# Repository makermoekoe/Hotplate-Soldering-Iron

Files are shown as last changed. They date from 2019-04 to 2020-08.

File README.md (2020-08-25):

# Hotplate Soldering Iron

__For more informations to this project you can visit my website [makermoekoe.com](https://www.makermoekoe.com)__

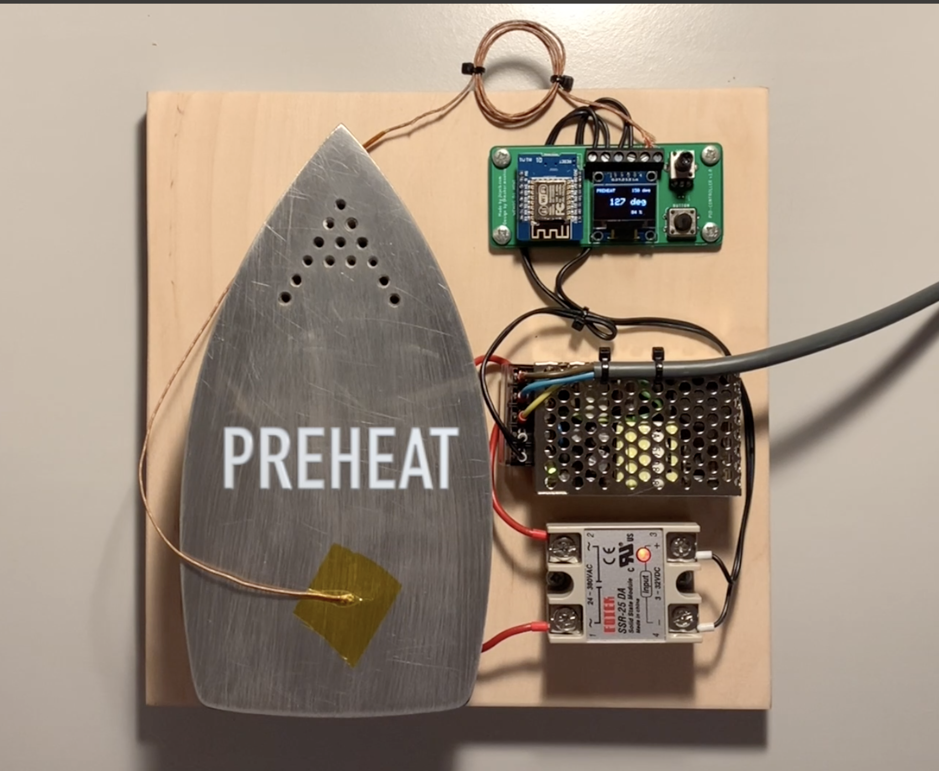
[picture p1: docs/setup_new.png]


(New version)



(Old version)

(Click on the images for a small video.)

Basic idea of the hotplate is slightly different from the standard tools like a reflow oven or soldering irons. The heat is supplied from the bottom of the PCB.

__What you will need:__

- an old iron
- microcontroller (I used a wemos d1 mini, but any will work)
- solid state relay 25A
- thermocouple sensor (a fast one...)
- 182x64 pixels oled display
- 5V DC power supply
- button, potentiometer and wires
- piece of wood and screws

Something similar is the Reflow Skillet from SparkFun: https://www.sparkfun.com/tutorials/59. They tested several methods to solder SMD components to PCBs and it turns out that their Skillet is the best solution for makers with a small budget. Inspired by this, my first thoughts about this old flatiron I found in the garage were to build a similar hot plate thing for soldering. And it turns out that this is working like a charm.

Concept of this is that the wemos d1 mini controls the solid state relay based on temperature informations from the thermocouple sensor, which I placed with some heat resistant kapton tape directly onto the iron (actually the sensor should be placed onto the PCB for preciser temperature readings). If you have a really fast iron than maybe you should use something like a PID controller. For me and my very sluggish iron a normal threshold based control is enough for now. I added my simple threshold code to this repository.

It takes about 3 minutes for the whole soldering process, which is very fast, compared to some professional solutions like reflow ovens. Maximal temperature is something about 220-240 degrees, depending on several things like used solder paste, PCB thickness, ...

__Conclusion:__

__Pro__
- works like a charm
- very low cost (I found all components at home)
- very fast soldering
- simple to build
- small frame size, suitable in every maker lab

__Cons__
- works only for one side of a PCB
- sluggish heat control of the iron (cool down takes several minutes). The PCB has to be removed after soldering process to cool down.

## Build your own

I have published two videos for creating the peace of wood used as base plate and for connecting the wires to the pcb. Just click on the images below to start the videos.

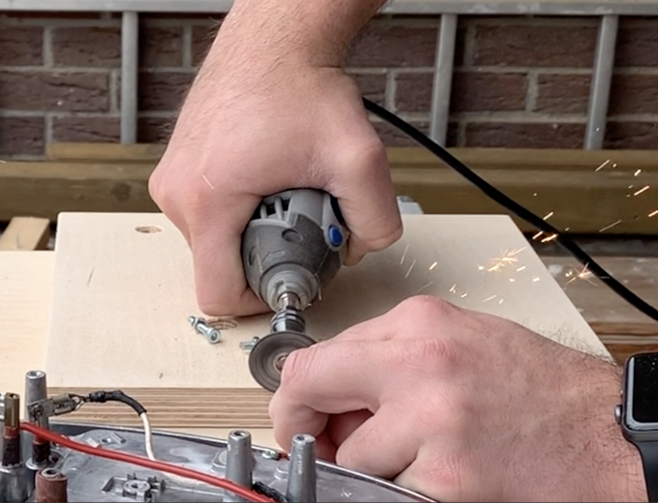
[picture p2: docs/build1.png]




When connecting the 230V power supply to your board be careful not to switch some wires, like I did :D

The three terminals are labeled with __SSR__ for solid state relay, __DC5V__ for the Wemos power supply and __Thermo__ for the thermocouple sensor. When switching the thermocouple sensor wires, the temperature on the display will get smaller when the plate gets hot. If this is the case, simply switch the __Thermo__ wires.

## Schematics

For the PCB I desoldered the MAX6675 thermocouple IC from the small breakout board and used it directly onto the PCB to safe a little bit of space. All other components are just connected via pin headers to the PCB. The 5V power supply, the thermocouple and the solid state relay on GPIO 8 are connected via those screw terminals.

<div>
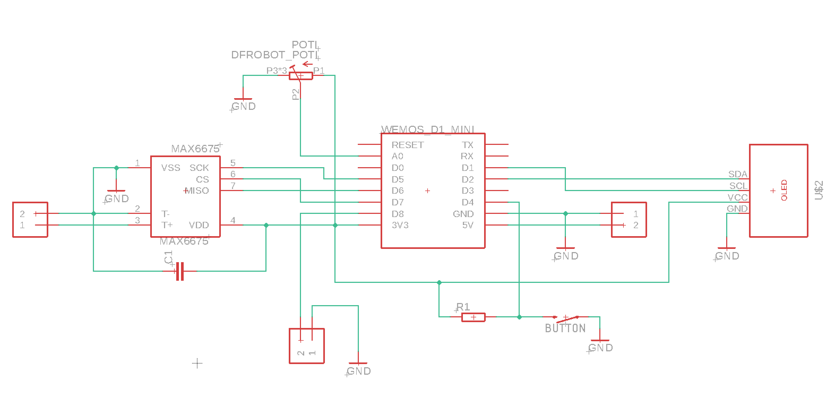
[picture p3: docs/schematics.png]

</div>

## Printed Circuit Board

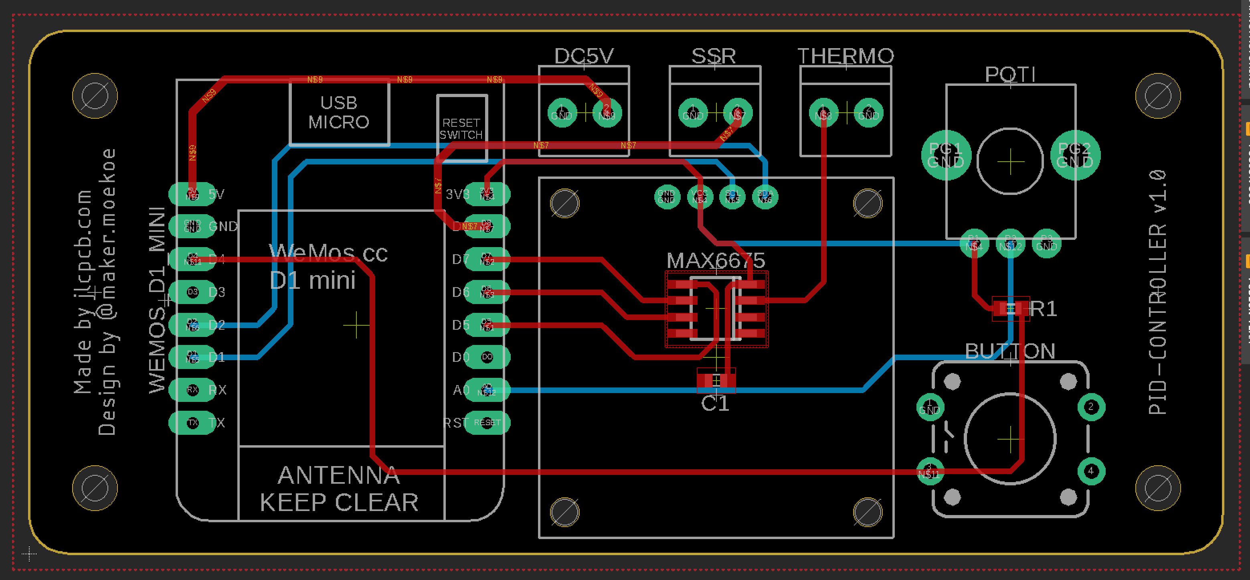
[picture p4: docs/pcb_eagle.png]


(Click on the image for a small video.)

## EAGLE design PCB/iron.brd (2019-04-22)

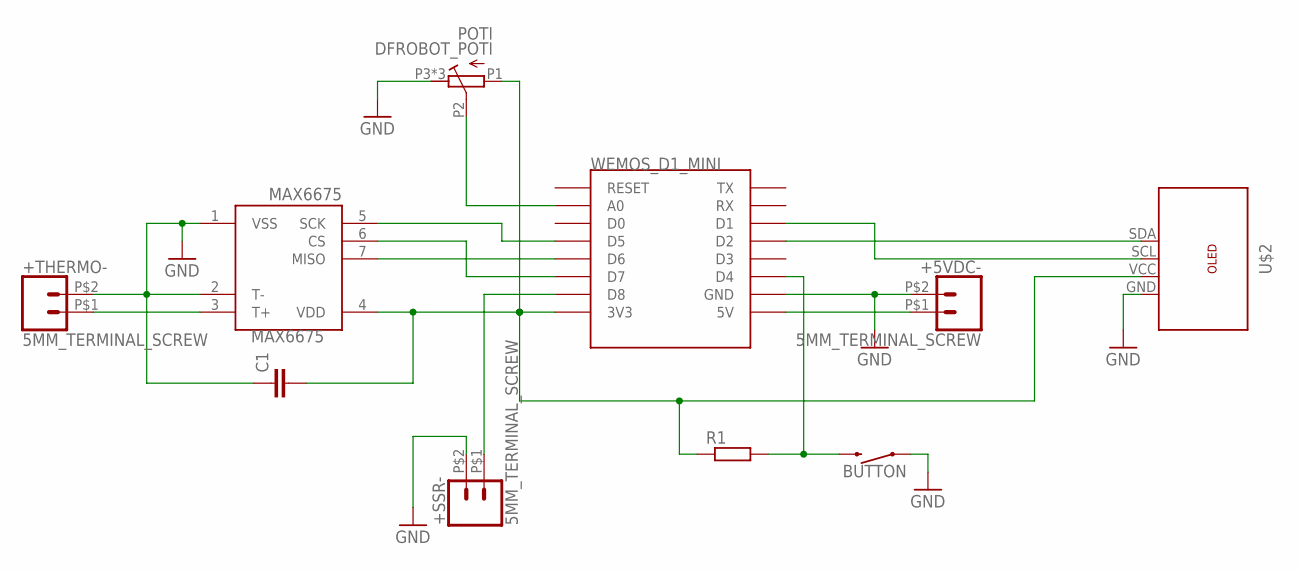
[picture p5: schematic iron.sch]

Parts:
+5VDC-: 5MM_TERMINAL_SCREW
+SSR-: 5MM_TERMINAL_SCREW
+THERMO-: 5MM_TERMINAL_SCREW
BUTTON: MOMENTARY-SWITCH-SPST-PTH-12MM; TACTILE_SWITCH_PTH_12MM
C1: C-EUC0603; C0603
MAX6675: MAX6675; SO08
POTI: DFROBOT_POTI
R1: R-EU_R0603; R0603
U$2: OLED128X64; OLED_128X64
WEMOS_D1_MINI: WEMOS-D1-MINI

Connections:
GND: +5VDC-.P$2 (2), +SSR-.P$2 (2), +THERMO-.P$2 (2), BUTTON.1, C1.1, MAX6675.1 (VSS), MAX6675.2 (T-), POTI.P3 (E), POTI.PG1 (E), POTI.PG2 (E), U$2.GND, WEMOS_D1_MINI.GND
unnamed: MAX6675.5 (SCK), WEMOS_D1_MINI.D5
unnamed: MAX6675.6 (CS), WEMOS_D1_MINI.D7
unnamed: MAX6675.7 (MISO), WEMOS_D1_MINI.D6
unnamed: C1.2, MAX6675.4 (VDD), POTI.P1 (A), R1.1, U$2.VCC, WEMOS_D1_MINI.3V3
unnamed: U$2.SCL, WEMOS_D1_MINI.D1
unnamed: U$2.SDA, WEMOS_D1_MINI.D2
unnamed: +SSR-.P$1 (1), WEMOS_D1_MINI.D8
unnamed: +THERMO-.P$1 (1), MAX6675.3 (T+)
unnamed: +5VDC-.P$1 (1), WEMOS_D1_MINI.5V
unnamed: BUTTON.3 (2), R1.2, WEMOS_D1_MINI.D4
unnamed: POTI.P2 (S), WEMOS_D1_MINI.A0

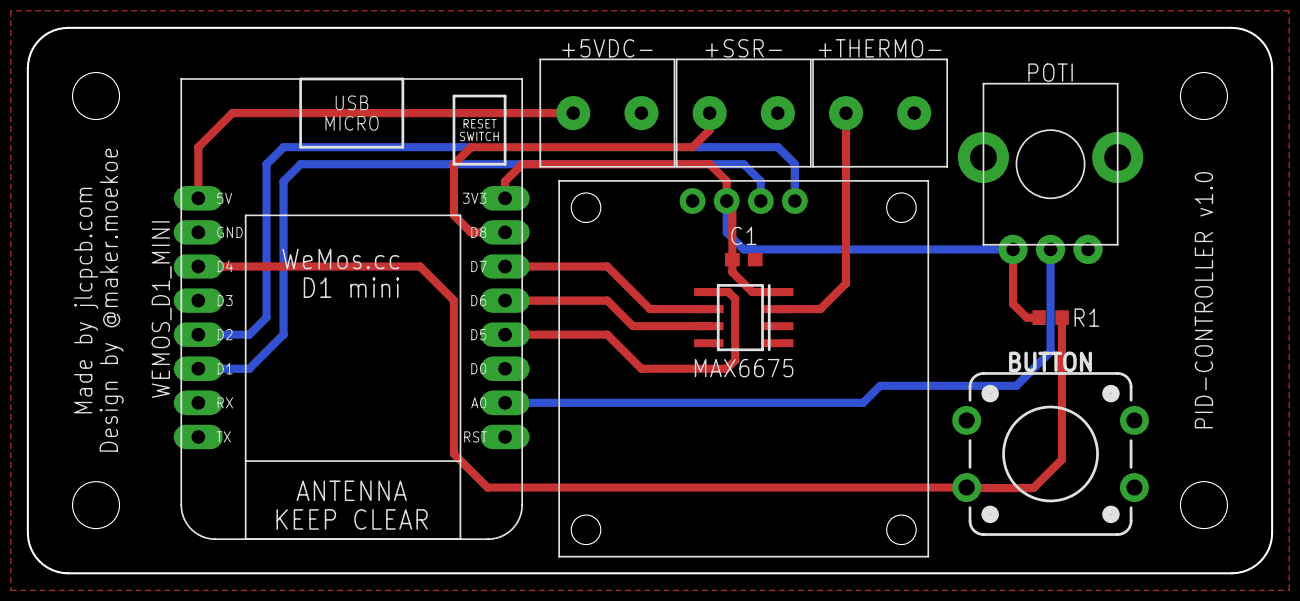
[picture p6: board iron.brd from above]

Board: 2 copper layers, 92.7 x 40.6 mm, 10 parts (0 on the bottom side), 12 nets.

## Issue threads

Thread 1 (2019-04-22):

PCB program

Slowre, 2019-04-22:
what program do you use to design the pcb

dedekcz, 2019-06-03:
looks like Eagle

skorokithakis, 2019-06-15:
Could we maybe get a Gerber export for fabrication? I use KiCAD and am not very familiar with Eagle, so it would take me a while to export.

makermoekoe, 2020-02-05:
Sorry for the late response...
Yes, I am using Eagle all the time.
@skorokithakis I have added the gerber files in the PCB section. But I am currently working on a new reflow controller which can be used for the iron as well.

Closed 2020-02-05.

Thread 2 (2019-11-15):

Resistor And Cap Values

Kperroch, 2019-11-15:
Hello @makermoekoe , what are the resistor R1 and Capacitor C1 values ?
They are not provided anywhere.

Many thanks

makermoekoe, 2020-02-05:
The values can be found on my website (I have linked it above the readme): https://www.makermoekoe.net/post/maker-moekoe-s-kind-of-soldering-iron

Value of R1 is 10k, value of C1 is 0.1µ and potentiometer is 10k as well

Closed 2020-02-05.

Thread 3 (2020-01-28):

Several problems , some questions

LordFennec, 2020-01-28:
Hello everyone. Congratulations on the project. I tried to make it but I ran into several problems.

Software: Arduino IDE 1.8.10 or Arduino IDE 1.6.13
Board: wemos D1 R1

1- with the max6675 library I have problems of this type:
F: \ Arduino-1.8.10 \ libraries \ MAX6675-library-master \ max6675.cpp: 9: 24: fatal error: util / delay.h: No such file or directory

  #include <util / delay.h>

Once the max6675.cpp library has been edited by deleting this string, I can compile it correctly, but it seems to me that it can correctly read the temperature

2- When I set a temperature with the potentiometer and press the button, nothing happens.

3- What kind of thermocouple did you use?

Where am I wrong? Tnks!!

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

LordFennec, 2020-02-04:
Is there anyone who managed to make it work ??

LordFennec, 2020-02-04:
is there anyone who managed to make it work ??

exiledyorkie, 2020-02-04:
Hi, I didn’t have problems with the lib, nor have to edit it but I switched out the Wemos for a Nano. I got it all working but I had a problem with the screens switching and unable to press the button. Turned out to be the power supply in the end. The thermo used is a K type. If nothing happens when the button is pressed, I’d assume there’s a connection issue and/or an issue with the Thermocouple, as the number looks rather large

LordFennec, 2020-02-04:
Hi and Tnks for your reply.
But how did you do to upload on a wemos using a Nano on the IDE?

exiledyorkie, 2020-02-05:
I didn’t. I uploaded onto a Nano via the Arduino IDE. I just adjusted the code slightly.

LordFennec, 2020-02-05:
WOuld you be kind enough to share the code or the modification you made? TNKS

makermoekoe, 2020-02-05:
Hey, sorry for the late response..
Can you tell me what PSU you are using? There are people out there which have used very noisy PSUs directly next to the Wemos D1 mini and the Wemos doesn't like it haha

LordFennec, 2020-02-05:
There is something that escapes me.
I have to program a Wemos D1 as if it were an Arduino Nano, okay?
In the Arduino IDE, select Arduino Nano as a board, do I choose the COM port. And the type of programmer?
Do I connect the wemos directly to the USB port or do I have to use the PINs on board?

makermoekoe, 2020-02-05:
Ooh no, there is something wrong in your mind... You have to choose Wemos D1 Mini board. When you couldn't find it in your board list, you have to [add ESP8266 via the boardmanager](https://github.com/esp8266/Arduino).

LordFennec, 2020-02-05:
No. then we didn't understand each other from the beginning.
I already have the cards installed in the card manager. Including esp8266 and wemos.
If I choose the wemos card I have compilation errors.
If I choose Arduino Nano as the board, No. But I can't load it on the wemos board
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

LordFennec, 2020-02-05:
Board manager and library all update

makermoekoe, 2020-02-05:
Try choosing the right board :D It is
LOLIN(WEMOS) D1 R2 & mini

LordFennec, 2020-02-05:
I tried with all the wemos versions available and the generic ESP8266. Always the usual error message on the MAX6675 library referred to

.... Arduino \ libraries \ MAX6675 \ max6675.cpp: 30: 14: error: '_delay_ms' was not declared in this scope

    _delay_ms (1);

LordFennec, 2020-02-05:
Can you show me your configuration?

exiledyorkie, 2020-02-05:
Hi. What I meant is, I switch to a Nano board. Not tried to upload Nano code to a D1 Mini. You have to set the board manager to the correct board.
Sorry, I have not got access to my code or images currently, but I followed the schematics exactly as they’re displayed in the tutorial.

exiledyorkie, 2020-02-05:
Which MAX6675 lib are you using?

makermoekoe, 2020-02-05:
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
And yes, make sure you download the correct MAX6675 lib. It is the Adafruit one which @exiledyorkie has mentioned above.

LordFennec, 2020-02-05:
I tried them all ... but nothing to do ... I can't compile it correctly.
Is there the possibility of having the firmware already compiled (.bin)? So I avoid using the arduino IDE?

exiledyorkie, 2020-02-05:
Tried them all, are you referring to the libs or board settings?

LordFennec, 2020-02-05:
Yes...

exiledyorkie, 2020-02-05:
Sorry I’m struggling to help here. Yes doesn’t answer the question to what I asked.

LordFennec, 2020-02-05:
As I explained above ... I tried the libraries indicated and with all the cards you suggested

LordFennec, 2020-02-05:
I summarize:

1- Uninstalled all the arduino environment.

2- Reinstalled version 1.8.11

3- ESP8266 boards added

4- Added adafruit ssd1306, GFX and max6675 libraries (latest versions)

5- Compiling the code on the Wemos D1 R1 board

_Error on <util / delay.h> (library max6675)_

6- Modified max6675.cpp file as follows:

_#elif defined (ESP8266)
   #include <pgmspace.h>
#define _delay_ms (ms) delayMicroseconds ((ms) * 1000)
#endif
// # include <util / delay.h>_

7- Code recompilation OK. No error

8- Temperature reading always at 0 ° (probable incorrect thermocouple). Same error if thermocouple disconnected.

Last fault found: temperature value writing moved too low on the display

relax81, 2020-02-06:
For the issue with your text being too low:

I guess it's handling your oled as a 128x32 and not 128x64

Try this
```
`#define SCREEN_WIDTH 128 // OLED display width, in pixels
#define SCREEN_HEIGHT 64 // OLED display height, in pixels`
Adafruit_SSD1306 display(SCREEN_WIDTH, SCREEN_HEIGHT, &Wire, OLED_RESET);
```

LordFennec, 2020-02-06:
Rightly .... I forgot to set it. now it's OK!!
I just need to check with another thermocouple k that should come to me tomorrow. We hope to solve everything

relax81, 2020-02-07:
One issue i was running into (not sure where it comes from) was that my temperature wasn't updated. I had to add a little delay to get it to work. Maybe i've too much noise or a bad max6675 (still usign perf board until the pcbs arrive)

```
#define SENSOR_SAMPLING_TIME 300
unsigned long nextRead;

void setup() {
 nextRead = millis();
}

void loop() {
  if (millis() > nextRead)
    {
      nextRead += SENSOR_SAMPLING_TIME;
      temp_now = thermocouple.readCelsius();
    }
}
```

Some other projects switched to the newer MAX31855 - maybe i'll try that one on a second board.

LordFennec, 2020-02-08:
Oohhh finally !!! I came to the head of this intrigue.

- Pre-Test: K thermocouple probe replaced but temperature result always at 0

- Final test: Rewired the whole circuit on breadboard. Test OK

- Conclusion: Integrated max6675 fault (tracks tested ok)

Replacing it will solve the problem (I hope).

However, all my changes to the max6675.cpp library remain valid, with the original adafruit library, it does not work.
I'm really happy. Considering that I understand absolutely nothing about programming. I did some experience :-)

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

LordFennec, 2020-02-09:
All Oookk!! I finally did it!

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

Closed 2020-02-09.

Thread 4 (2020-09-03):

Halogen soldering setup improvement

joustava, 2020-09-03:
Interesting DIY setup to do DIY SMD soldering. I have read the sparkfun article and then the article on your WP site. I however noticed somewhere that you made another SMD soldering setup with a halogen lamp. I was wondering if the plans for that can be found from somewhere? Would be great if I could try and make that version as my hands and eyes are not incredibly good to do smd soldering by hand.
Do you have a good resource on what kind of flux and paste one should use?
Tried to post this on your site but it didn't work.

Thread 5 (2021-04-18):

Temperature not updated

patzik, 2021-04-18:
One issue i was running into (not sure where it comes from) was that my temperature wasn't updated. I had to add a little delay to get it to work. Maybe i've too much noise or a bad max6675 (still usign perf board until the pcbs arrive)

```
#define SENSOR_SAMPLING_TIME 500
unsigned long nextRead;

void setup() {
 nextRead = millis();
}

void loop() {
  if (millis() > nextRead)
    {
      nextRead += SENSOR_SAMPLING_TIME;
      temp_now = thermocouple.readCelsius();
    }
}
```

Some other projects switched to the newer MAX31855 - maybe i'll try that one on a second board.

_Originally posted by @relax81 in https://github.com/makermoekoe/Hotplate-Soldering-Iron/issues/3#issuecomment-583648991_

patzik, 2021-04-18:
I am having the same issue that the temperature is not being updated. When I switch between the modes it gets updated once and then hangs at this temperature again. I found this solution in a previous issue but I can't seem to add it at the right place into the ino file. Maybe someone can help me with this.
I also had the display problem and this was solved with the solution provided in the same issue.
I did have to use an older version of the esp8266 boards, as the latest version did not work.
It would help if the versions of the boards and libraries used to compile was known.

TamojitSaha, 2021-05-06:
>
>
> I am having the same issue that the temperature is not being updated. When I switch between the modes it gets updated once and then hangs at this temperature again. I found this solution in a previous issue but I can't seem to add it at the right place into the ino file. Maybe someone can help me with this.

I was having the same problem and with the help from [here](https://github.com/makermoekoe/Hotplate-Soldering-Iron/issues/3#issuecomment-583648991) as pointed by @patzik I managed to solved the issue.

In the code below please comment out the corresponding of `Serial.print` if not required.

Below is the source code:

```C
#include <SPI.h>
#include <Wire.h>
#include <Adafruit_GFX.h>
#include <Adafruit_SSD1306.h>
#include "max6675.h"

#define SCREEN_WIDTH 128 // OLED display width, in pixels
#define SCREEN_HEIGHT 64 // OLED display height, in pixels

#define COOLDOWN_TIME 60 //60
#define PREHEAT_TIME 60
#define REFLOW_TIME 60

#define SENSOR_SAMPLING_TIME 500
unsigned long nextRead;

#define OLED_RESET -1  // GPIO0
Adafruit_SSD1306 display(SCREEN_WIDTH, SCREEN_HEIGHT, &Wire, OLED_RESET);

int thermoDO = 12;
int thermoCS = 13;
int thermoCLK = 14;

MAX6675 thermocouple(thermoCLK, thermoCS, thermoDO);

const int button = 2;
const int solidstate = 15;

const int temp_preheat = 150;
const int temp_reflow = 240;

int temp_now = 0;
int temp_next = 0;
String state[] = {"OFF", "PREHEAT", "REFLOW", "COOLING"};
int state_now = 0;

int time_count = 0;
int perc = 0;

int offset = 0;

void setup() {
  pinMode(button, INPUT_PULLUP);
  pinMode(solidstate, OUTPUT);
  digitalWrite(solidstate, LOW);
  display.begin(SSD1306_SWITCHCAPVCC, 0x3C);
  display.clearDisplay();
  display.display();
  Serial.begin(115200);
  nextRead = millis();
}

long t = millis();
long t_solder = millis();

void loop() {
//  temp_now = thermocouple.readCelsius();
    if (millis() > nextRead)
    {
      nextRead += SENSOR_SAMPLING_TIME;
      temp_now = thermocouple.readCelsius();
    }

  if (millis() > t + 200 || millis() < t) {
    Serial.print("Temp:");Serial.println(temp_now);
    PrintScreen(state[state_now], temp_next, temp_now, time_count, perc);
    t = millis();
  }

  if (digitalRead(button) == 0) {
    delay(100);
    int c = 0;
    while (digitalRead(button) == 0)
    {
      c++;
      if (c > 150) {
        digitalWrite(solidstate, LOW);
        state_now = 0;
        display.fillScreen(WHITE);
        display.setTextColor(BLACK);
        display.setTextSize(2);
        display.setCursor(X(2, 3), Y(2, 0.5));
        display.println("OFF");
        display.display();
        while (digitalRead(button) == 0) delay(1);
        return;
      }
      delay(10);
    }

    t_solder = millis();
    perc = 0,
    state_now++;
    if (state_now == 0) temp_next = 0;
    else if (state_now == 1) temp_next = temp_preheat;
    else if (state_now == 2) temp_next = temp_reflow;
    else if (state_now == 3) temp_next = 0;
    else if (state_now == 4) state_now = 0;
  }

  if (state_now == 1) { //PREHEAT
    regulate_temp(temp_now, temp_next);

    perc = int((float(temp_now) / float(temp_next)) * 100.00);
  }
  else if (state_now == 2) { //REFLOW
    regulate_temp(temp_now, temp_next);

    perc = int((float(temp_now) / float(temp_next)) * 100.00);
    if (perc >= 100) {
      state_now = 3;
      t_solder = millis();
      perc = 0;
      temp_next = 0;
    }
  }
  else if (state_now == 3) { //COOLING
    digitalWrite(solidstate, LOW);

    time_count = int((t_solder + COOLDOWN_TIME * 1000 - millis()) / 1000);
    if (time_count <= 0) {
      state_now = 0;
    }
  }
  else {
    digitalWrite(solidstate, LOW);
    time_count = 0;
  }

  delay(50);
}

void regulate_temp(int temp, int should) {
  if (should < temp - offset) {
    digitalWrite(solidstate, LOW);
  }
  else if (should > temp + offset) {
    digitalWrite(solidstate, HIGH);
  }
}

void PrintScreen(String state, int soll_temp, int ist_temp, int tim, int percentage) {
  display.clearDisplay();
  display.setTextColor(WHITE);
  display.setTextSize(1);
  display.setCursor(0, 0);
  display.println(state);

  display.setCursor(80, 0);
  String str = String(soll_temp) + " deg";
  display.println(str);

  if (tim != 0) {
    display.setCursor(0, 50);
    str = String(tim) + " sec";
    display.println(str);
  }

  if (percentage != 0) {
    display.setCursor(80, 50);
    str = String(percentage) + " %";
    display.println(str);
  }

  display.setTextSize(2);
  display.setCursor(30, 22);
  str = String(ist_temp) + " deg";
  display.println(str);

  display.display();
}

int X(int textgroesse, int n) {
  //gibt die X koordinate aus, damit text mit n zeichen mittig ist

  return (0.5 * (display.width() - textgroesse * (6 * n - 1)));
}//end int X

int Y(int textgroesse, float f) {
  //gibt die Y koordinate aus, damit text mittig ist

  return (f * display.height() - (textgroesse * 4));
}//end int Y
```

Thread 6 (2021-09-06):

Component Values

factotumindustries, 2021-09-06:
Hey there!

VR1, R1 and C1 do not seem to have values in the schematic :(

I'm building a list from Mouser.

Switch is 474-COM-09190

And which OLED did you originally use?

Thanks!

chmutoff, 2021-09-24:
Value of R1 is 10k, value of C1 is 0.1µ and potentiometer is 10k as well.

You will not find the display on Mouser or similar sites. I´ts from aliexpress
https://aliexpress.com/item/32643950109.html

Please, read the original article
https://makermoekoe.com/2020/04/28/maker-moekoes-kind-of-soldering-iron/

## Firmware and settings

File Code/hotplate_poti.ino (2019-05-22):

#include <SPI.h>
#include <Wire.h>
#include <Adafruit_GFX.h>
#include <Adafruit_SSD1306.h>
#include "max6675.h"


#define COOLDOWN_TIME 60 //60
#define PREHEAT_TIME 60
#define REFLOW_TIME 60


#define OLED_RESET 0  // GPIO0
Adafruit_SSD1306 display(OLED_RESET);

int thermoDO = 12;
int thermoCS = 13;
int thermoCLK = 14;

MAX6675 thermocouple(thermoCLK, thermoCS, thermoDO);

const int button = 2;
const int solidstate = 15;
const int poti = A0;


const int temp_preheat = 150;
const int temp_reflow = 240;

int temp_now = 0;
int temp_next = 0;
int temp_poti = 0;
int temp_poti_old = 0;
String state[] = {"OFF", "PREHEAT", "REFLOW", "COOLING"};
int state_now = 0;

int time_count = 0;
int perc = 0;

int offset = 0;

void setup() {
  pinMode(button, INPUT);
  pinMode(solidstate, OUTPUT);
  digitalWrite(solidstate, LOW);
  display.begin(SSD1306_SWITCHCAPVCC, 0x3C);
  display.clearDisplay();
  display.display();
}

long t = millis();
long t_solder = millis();

void loop() {
  temp_now = thermocouple.readCelsius();

  temp_poti = map(analogRead(poti), 1023, 0, temp_preheat, temp_reflow);

  if (temp_poti != temp_poti_old) {
    int v = 0;
    display.fillScreen(WHITE);
    display.setTextColor(BLACK);
    display.setTextSize(1);
    display.setCursor(X(1, 7), Y(1, 0.1));
    display.println("PREHEAT");
    display.setTextSize(2);
    display.setCursor(X(2, 3), Y(2, 0.5));
    while (v < 100) {
      temp_poti = map(analogRead(poti), 1023, 0, temp_preheat, temp_reflow);
      if (temp_poti > temp_poti_old + 1 || temp_poti < temp_poti_old - 1) {
        display.fillScreen(WHITE);
        display.setTextSize(1);
        display.setCursor(X(1, 6), Y(1, 0.1));
        display.println("REFLOW");
        display.setTextSize(2);
        display.setCursor(X(2, 3), Y(2, 0.5));
        display.println(String(temp_poti));
        display.display();
        temp_poti_old = temp_poti;
        v = 0;
      }
      v++;
      delay(20);
    }
    temp_poti_old = temp_poti;
  }

  if (millis() > t + 200 || millis() < t) {
    PrintScreen(state[state_now], temp_next, temp_now, time_count, perc);
    t = millis();
  }


  if (digitalRead(button) == 0) {
    delay(100);
    int c = 0;
    while (digitalRead(button) == 0) {
      c++;
      if (c > 150) {
        digitalWrite(solidstate, LOW);
        state_now = 0;
        display.fillScreen(WHITE);
        display.setTextColor(BLACK);
        display.setTextSize(2);
        display.setCursor(X(2, 3), Y(2, 0.5));
        display.println("OFF");
        display.display();
        while (digitalRead(button) == 0) delay(1);
        return;
      }
      delay(10);
    }

    t_solder = millis();
    perc = 0,
    state_now++;
    if (state_now == 0) temp_next = 0;
    else if (state_now == 1) temp_next = temp_preheat;
    else if (state_now == 2) temp_next = temp_poti;
    else if (state_now == 3) temp_next = 0;
    else if (state_now == 4) {
      state_now = 0;
      temp_next = 0;
    }
  }


  if (state_now == 1) { //PREHEAT
    regulate_temp(temp_now, temp_next);

    perc = int((float(temp_now) / float(temp_next)) * 100.00);
  }
  else if (state_now == 2) { //REFLOW
    regulate_temp(temp_now, temp_next);

    perc = int((float(temp_now) / float(temp_next)) * 100.00);
    if (perc >= 100) {
      state_now = 3;
      t_solder = millis();
      perc = 0;
      temp_next = 0;
    }
  }
  else if (state_now == 3) { //COOLING
    digitalWrite(solidstate, LOW);

    time_count = int((t_solder + COOLDOWN_TIME * 1000 - millis()) / 1000);
    if (time_count <= 0) {
      state_now = 0;
    }
  }
  else {
    digitalWrite(solidstate, LOW);
    time_count = 0;
  }

  delay(30);
}




void regulate_temp(int temp, int should) {
  if (should <= temp - offset) {
    digitalWrite(solidstate, LOW);
  }
  else if (should > temp + offset) {
    digitalWrite(solidstate, HIGH);
  }
}


void PrintScreen(String state, int soll_temp, int ist_temp, int tim, int percentage) {
  display.clearDisplay();
  display.setTextColor(WHITE);
  display.setTextSize(1);
  display.setCursor(0, 0);
  display.println(state);

  display.setCursor(80, 0);
  String str = String(soll_temp) + " deg";
  display.println(str);

  if (tim != 0) {
    display.setCursor(0, 50);
    str = String(tim) + " sec";
    display.println(str);
  }

  if (percentage != 0) {
    display.setCursor(80, 50);
    str = String(percentage) + " %";
    display.println(str);
  }

  display.setTextSize(2);
  display.setCursor(30, 22);
  str = String(ist_temp) + " deg";
  display.println(str);

  display.display();
}


int X(int textgroesse, int n) {
  //gibt die X koordinate aus, damit text mit n zeichen mittig ist

  return (0.5 * (display.width() - textgroesse * (6 * n - 1)));
}//end int X

int Y(int textgroesse, float f) {
  //gibt die Y koordinate aus, damit text mittig ist

  return (f * display.height() - (textgroesse * 4));
}//end int Y

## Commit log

2019-04-22 added PCB
    [iron.brd, iron.sch]
2020-02-05 added gerber
    [copper_bottom.gbr, copper_top.gbr, drills.xln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]

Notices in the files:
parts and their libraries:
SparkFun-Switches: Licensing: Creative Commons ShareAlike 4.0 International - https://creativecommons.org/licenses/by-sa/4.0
